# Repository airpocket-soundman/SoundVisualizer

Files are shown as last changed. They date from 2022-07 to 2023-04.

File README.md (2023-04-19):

# SoundVisualizer
Sound visualization device using Sipeed MaixBit.  
https://www.youtube.com/watch?v=WP3SPSRaIhk<BR>
https://protopedia.net/prototype/2547<BR>
https://hackaday.io/project/190651-portable-sound-visualization-device<BR>

# Parts list
maixbit  
6+1 mic array  
lens  
https://ja.aliexpress.com/item/32804179806.html?gatewayAdapt=glo2jpn  
AAA battery case x 2  
Qi connector & cable (connect microbit to micarray)  
Universal board  
some cables(connect battery,toggle switch)  
some screws  

# 3D data

view stl folder

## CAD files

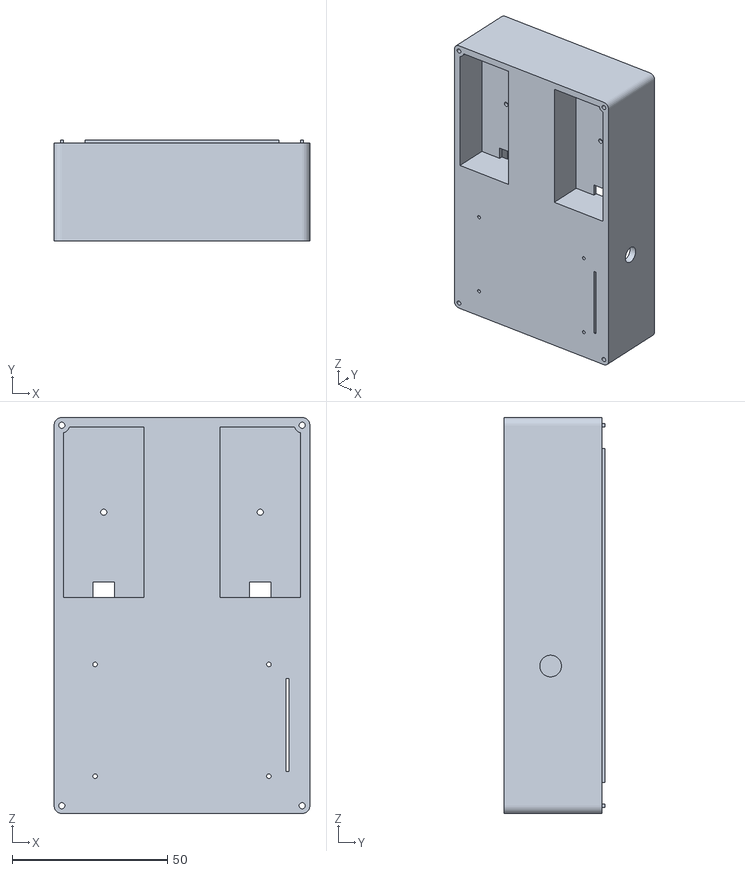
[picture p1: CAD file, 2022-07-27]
stl/mic array case B3 v5.stl
82.4 x 32.5 x 127.5

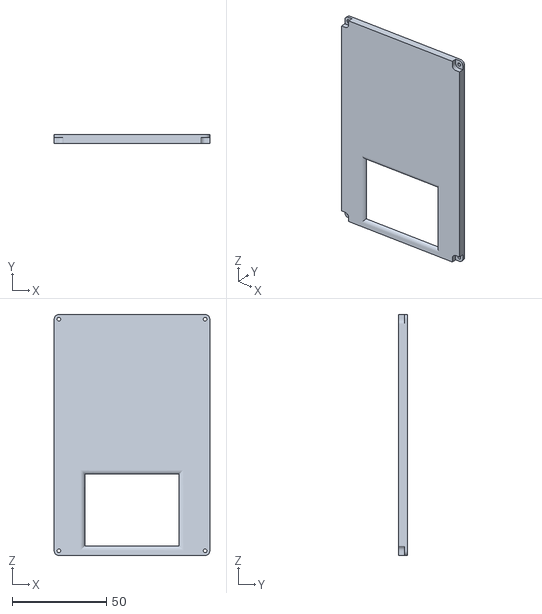
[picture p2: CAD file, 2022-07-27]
stl/mic array case C3 v3.stl
82.4 x 4.50 x 127.5

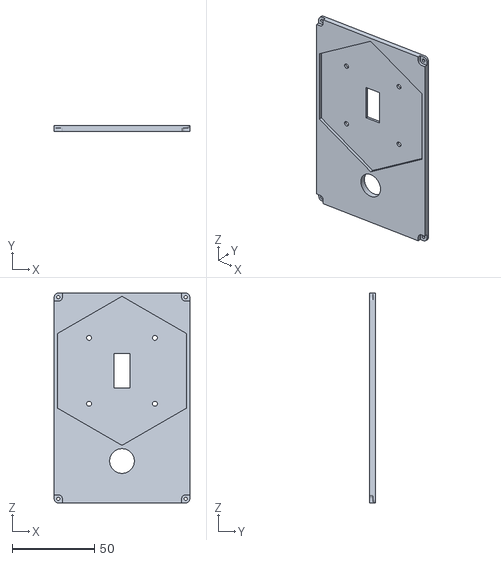
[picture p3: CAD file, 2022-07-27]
stl/mic array case A3 v4.stl
82.4 x 3.50 x 127.5

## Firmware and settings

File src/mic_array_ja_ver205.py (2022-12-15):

#v205 グレイマップ出力機能追加
#v204 v203の英語注釈版
#v203 コメント修正
#v202 heap mem
#v201 Qiitaアップ版
#v200 soundmap 拡大率調整版

from Maix import MIC_ARRAY as mic
from Maix import FPIOA
from fpioa_manager import fm
import lcd
import sensor
import gc

from Maix import utils      #heap mem使用量確認及び設定用
utils.gc_heap_size(2500000) #Heap mem山盛り設定　soundmap画像を480*480に引き伸ばし処理するため増量必要。

lcd.init()
lcd.direction(lcd.YX_LRDU)   #soundmapとcameraイメージの向き合わせのため、hmirrorとvflipと組み合わて使用。
sensor.reset()
sensor.set_auto_gain(1)             #自動ゲインは入れましょう。
sensor.set_auto_whitebal(1)         #自動WBも入れましょう
sensor.set_pixformat(sensor.RGB565)
sensor.set_framesize(sensor.QVGA)
sensor.set_hmirror(3)
sensor.set_vflip(0)
sensor.run(1)

mic.init()
Fpioa = FPIOA()
LEDdir = (0,0,0)            #マイクアレイモジュールのLEDインジケーター表示。RGBの輝度を0-255で設定。まぶしいのでいらない。

#Maxi Bit用のピン設定。
Fpioa.set_function(23, fm.fpioa.I2S0_IN_D0);
Fpioa.set_function(22, fm.fpioa.I2S0_IN_D1);
Fpioa.set_function(21, fm.fpioa.I2S0_IN_D2);
Fpioa.set_function(20, fm.fpioa.I2S0_IN_D3);
Fpioa.set_function(19, fm.fpioa.I2S0_WS);
Fpioa.set_function(18, fm.fpioa.I2S0_SCLK);
Fpioa.set_function(17, fm.fpioa.GPIOHS28);
Fpioa.set_function(15, fm.fpioa.GPIOHS27);

while True:

    img = sensor.snapshot()                         #カメラ画像取得

    soundmap = mic.get_map()                        #マイクアレイから音源の推定位置を16*16pixelのgrayscaleで求める。
    sumM = 0
    sumMx = 0
    sumMy = 0
    grayMap = []
    for mapx in range(16):
        grayLine = []
        for mapy in range(16):
            sumM = sumM + soundmap.get_pixel(mapx,mapy)
            sumMx = sumMx + (mapx * soundmap.get_pixel(mapx,mapy))
            sumMy = sumMy + (mapy * soundmap.get_pixel(mapx,mapy))
            grayLine.append(soundmap.get_pixel(mapx,mapy))
#        print(grayLine)
        grayMap.append(grayLine)
#    if sumM > 0:
#        print(sumMx/sumM,sumMy/sumM)
    print(grayMap)
    sounddir = mic.get_dir(soundmap)                #soundmapから音源方向を求める？
    mic.set_led(sounddir,(LEDdir))                  #マイクアレイモジュールのLEDを光らせる。
    soundmap = soundmap.copy((2,4,12,8))            #サウンドマップの画格をカメラに合わせるため、中央8*6pixcelを切り出す

    soundmap = soundmap.resize(320,240)             #サウンドマップをカメラ画像に合わせるため320*240pixelに拡大
    maskmap = soundmap.copy()                       #soundmapとカメラ画像を合成する際のマスク様画像を作成
    maskmap = maskmap.binary([(1,255)])             #maskmapを二値化してマスクにする。
    soundmap = soundmap.to_rainbow(1)               #soudnmapをレインボーカラーに変更
#    img = img.copy((30,0,240,240))                 #合成する前にカメラ画像をsoundmapとサイズ合わせる。
    img.blend(soundmap,alpha = 150,mask = maskmap)  #マスクを使い、soundmapの音検出部分のみをカメラ画像に重ね合わせる。alpha値が大きいほど音の表示が薄くなる。
    lcd.display(img)

mic.deinit()

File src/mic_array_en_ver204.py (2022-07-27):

#v204 The comments were translated into English.
#v203 Corrected comment. 
#v202 Changed heap mem size.
#v201 Qiita version
#v200 The magnification rate of the sound pressure map was changed with the lens change.

from Maix import MIC_ARRAY as mic
from Maix import FPIOA
from fpioa_manager import fm
import lcd
import sensor
import gc

from Maix import utils      #For checking and setting heap mem usage
utils.gc_heap_size(2500000) #Heap mem heap setting. Increased volume is required to process soundmap images stretched to 480*480.

lcd.init()
lcd.direction(lcd.YX_LRDU)   #Used in combination with hmirror and vflip to align soundmap and camera image orientation.
sensor.reset()
sensor.set_auto_gain(1)             #Automatic gain should enabled.
sensor.set_auto_whitebal(1)         #Auto WB should also be enabled.
sensor.set_pixformat(sensor.RGB565)
sensor.set_framesize(sensor.QVGA)
sensor.set_hmirror(3)
sensor.set_vflip(0)
sensor.run(1)

mic.init()
Fpioa = FPIOA()
LEDdir = (100,100,100)            #LED indicator display on the microphone array module, with RGB brightness set from 0-255. Not needed because of glare.

#Maxi Bit用のピン設定。
Fpioa.set_function(23, fm.fpioa.I2S0_IN_D0);
Fpioa.set_function(22, fm.fpioa.I2S0_IN_D1);
Fpioa.set_function(21, fm.fpioa.I2S0_IN_D2);
Fpioa.set_function(20, fm.fpioa.I2S0_IN_D3);
Fpioa.set_function(19, fm.fpioa.I2S0_WS);
Fpioa.set_function(18, fm.fpioa.I2S0_SCLK);
Fpioa.set_function(17, fm.fpioa.GPIOHS28);
Fpioa.set_function(15, fm.fpioa.GPIOHS27);

while True:

    img = sensor.snapshot()                         #Get camera image.

    soundmap = mic.get_map()                        #Estimated position of the sound source from the microphone array in 16*16pixel grayscale.
    sounddir = mic.get_dir(soundmap)                #Find sound source direction from soundmap.
    mic.set_led(sounddir,(LEDdir))                  #Light up the LEDs on the microphone array module.
    soundmap = soundmap.copy((2,4,12,8))            #Cut out the center 8*6 pixcel to match the picture scale of the sound map to the camera.
    soundmap = soundmap.resize(320,240)             #Enlarge sound map to 320*240pixel to match camera image
    maskmap = soundmap.copy()                       #Create mask-like image when combining soundmap and camera image
    maskmap = maskmap.binary([(1,255)])             #Binarize maskmap to mask.
    soundmap = soundmap.to_rainbow(1)               #Change soudnmap to rainbow color.
    img.blend(soundmap,alpha = 150,mask = maskmap)  #By using a mask, only the sound detection portion of the sound map can be overlaid on the camera image. 
                                                    #The higher the alpha value, the fainter the sound is displayed.
    lcd.display(img)

mic.deinit()

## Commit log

2022-07-27 first
    first
    [mic array case A3 v4.stl, mic array case B3 v5.stl, mic array case C3 v3.stl]
2022-12-15 グレーマップシリアル出力追加
